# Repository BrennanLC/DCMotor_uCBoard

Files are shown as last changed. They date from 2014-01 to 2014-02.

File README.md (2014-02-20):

DCMotor_uCBoard
===============

ATmega328P Microcontroller Board with 2-CH DC Motor Driver

Design has not yet been verified. Build at your own risk!

Files:

MDM00001.sch - Board schematic eagle file

MDM00001.pdf - Board schematic PDF file

MDM00001.brd - Board layout eagle file

MDM00001Board.pdf - Board layout PDF file

schematic and board layout built with Eagle 6.4.0 Standard. More info and 
download available here:

https://www.cadsoftusa.com/

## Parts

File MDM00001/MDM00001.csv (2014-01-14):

Qty | Value | Device | Package | Parts | Description | DIGIKEYPART# | PART# | PROD_ID
4 |  | LED0603 | LED-0603 | LED1, LED2, LED3, LED4 | LEDs
1 |  | M05PTH | 1X05 | JP4 | Header 5
1 |  | PINHD-2X3 | 2X03 | JP10 | PIN HEADER
1 |  | RESONATORPTH | RESONATOR-PTH | Y1 | Resonator
7 | 0.1uF | CAP0603-CAP | 0603-CAP | C1, C4, C5, C10, C11, C12, C13 | Capacitor
3 | 10k | RESISTOR0603-RES | 0603-RES | R2, R7, R8 | Resistor
3 | 10uF | CAP_POL_AL | PANASONIC_BMIN | C3, C7, C8 | Panasonic Aluminum Electrolytic Capacitor Package B
2 | 1k | RESISTOR0603-RES | 0603-RES | R11, R12 | Resistor
2 | 2-TERMINAL | 2-TERMINAL | OSTTA020161 | JP1, JP3 | 2-Terminal Header. Based on OSTTA020161 | ED2561-ND | OSTTA020161
4 | 270 | RESISTOR0603-RES | 0603-RES | R3, R4, R9, R10 | Resistor
1 | 3SMAJ5926B-TP | 3SMAJ5926B-TP | DO-214AC | CR17 | 3SMAJ5926B-TP, 3W SMD Zener Diode, 11V Regulator | 3SMAJ5926B-TPMSCT-ND
1 | ATMEGA328P_PDIP | ATMEGA328P_PDIP | DIL28-3 | U1 | uC used in the Arduino
1 | CD4011BM | CD4011BM | 14-SOIC | U3 | CD4011 Quad NAND gate discrete logic IC | 296-14474-1-ND
2 | DRV8837DSGR | DRV8837DSGR | 8-WSON | U5, U6 | DRV8837DSGR, DC Motor Driver IC see datasheet for more information datasheet | 296-34806-1-ND
1 | FDN340P | MOSFET-PCHANNELSMD | SOT23-3 | Q1 | Generic PMOSFET
1 | FT232RLSSOP | FT232RLSSOP | SSOP28DB | U9 | USB UART |  |  | IC-00870
1 | LMV358 | LMV358 | SO08 | U$3 | Jellybean rail-to-rail output op-amp |  |  | IC-09657
1 | NCP1117ST50T3G | NCP1117ST50T3G | SOT223 | U4 | NCP1117 5V, 1.0 A Low-Dropout Positive Fixed and Adjustable Voltage Regulator Datasheet | NCP1117ST50T3GOSCT-ND
1 | POWER_JACKPTH | POWER_JACKPTH | POWER_JACK_PTH | J1 | Power Jack
1 | PTCSMD | PTCSMD | PTC-1206 | F1 | Resettable Fuse PTC
8 | SMD26PL | SMD26PL | SOD-123FL | CR1, CR2, CR3, CR4, CR5, CR6, CR7, CR8 | Schottky Barrier Diode SMD26PL | SMD26PL-TPMSCT-ND
1 | SN74HC02DR | SN74HC02DR | 14-SOIC | U10 | SN74HC02DR, Quad, Dual Input Nor Gate | 296-1188-1-ND
4 | STAND-OFF | STAND-OFF | STAND-OFF | STANDOFF1, STANDOFF2, STANDOFF3, STANDOFF4 | #4 Stand Off
1 | SWITCH | SWITCH-MOMENTARY-2PTH | TACTILE-PTH | S1 | Various NO switches- pushbuttons, reed, etc
1 | USBSMD | USBSMD | USB-MINIB | JP2 | USB Connectors

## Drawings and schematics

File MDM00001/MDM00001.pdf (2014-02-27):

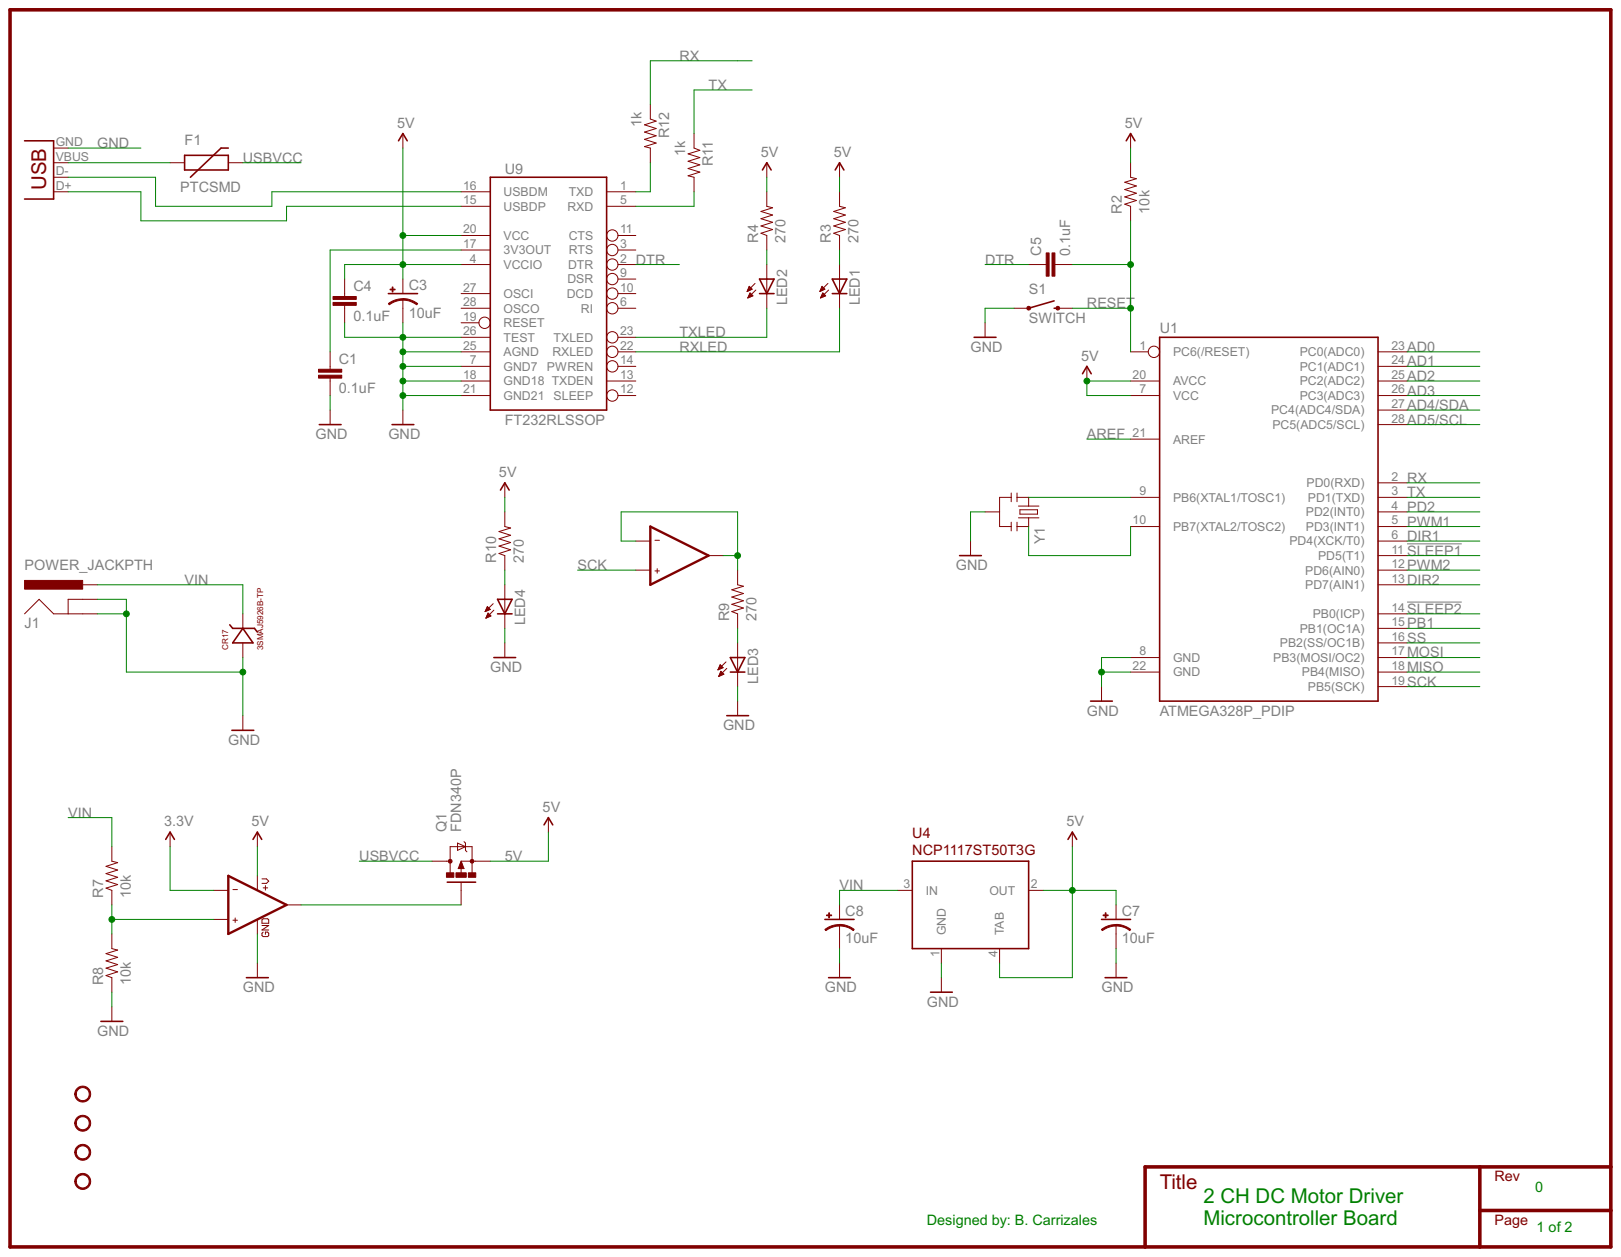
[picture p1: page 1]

Title
2 CH DC Motor Driver

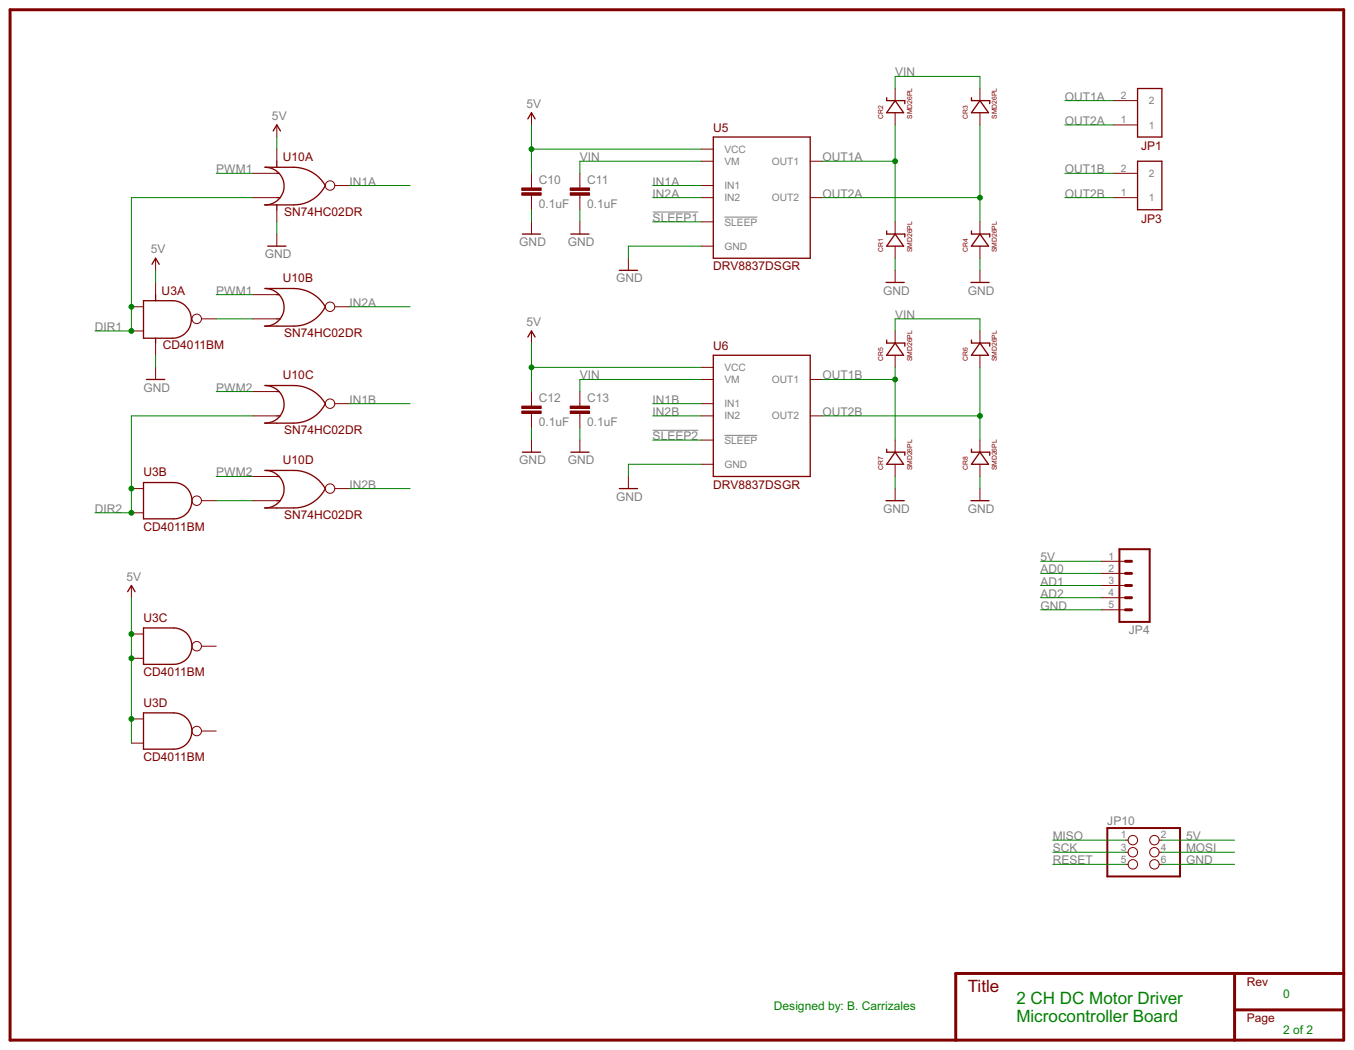
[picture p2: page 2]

2 CH DC Motor Driver
Microcontroller Board

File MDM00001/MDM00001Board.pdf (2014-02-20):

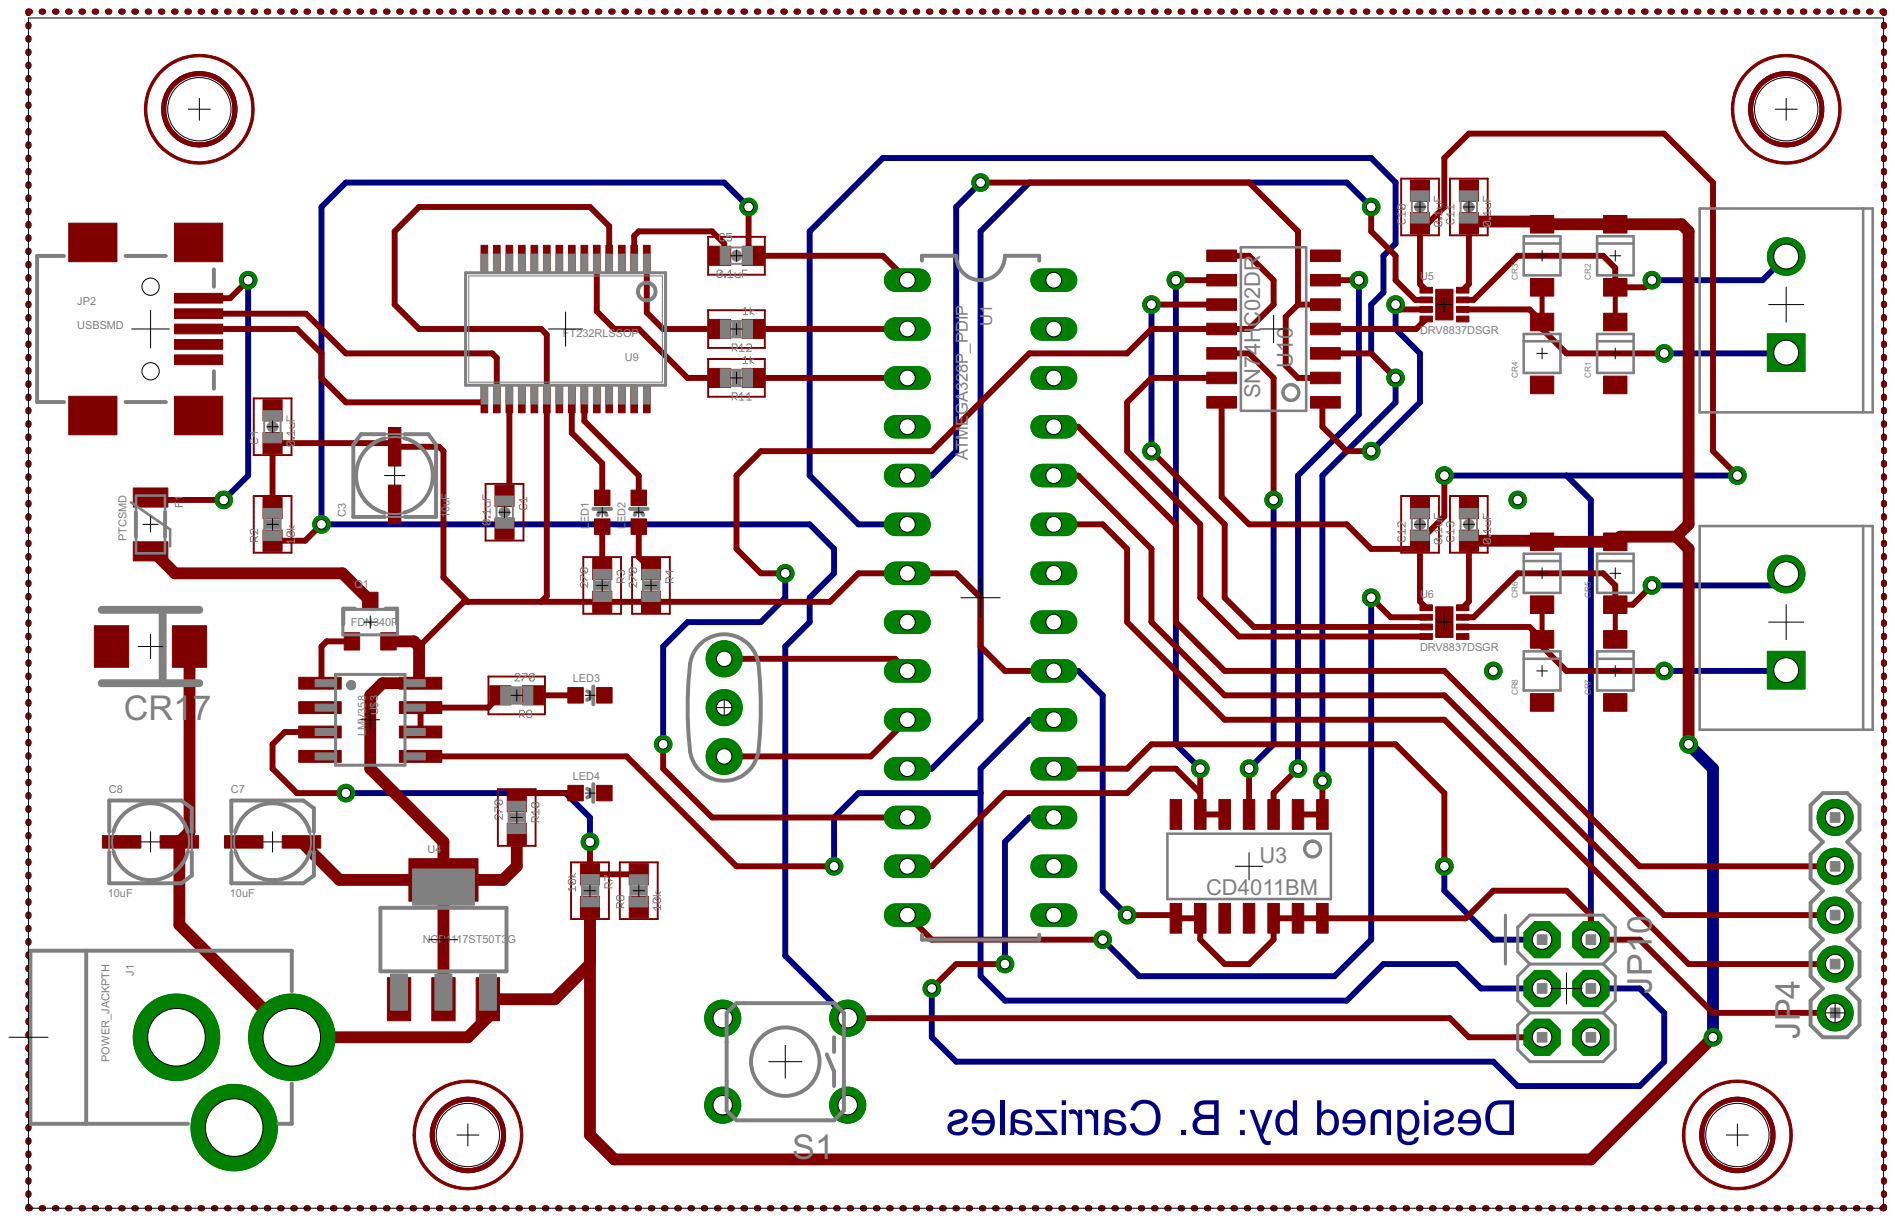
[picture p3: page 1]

sel azirr aC. B: yb dengi seD U5DRV8837DSGR U6DRV8837DSGR CR17 CD4011BM U3SN74HC02DR U10U1JP2 LED1 LEDF21 J1 CR1 CR2 CR3 CR4 CR5 CR6 CR7 CR8 JP10 U$3 Q1 LED3 LED4 U4 C8 C7 S1 C3 U9 JP4 ATMEGA328P_PDIP USBSMD PTCSMD POWER_JACKPTH LMV358 FDN340P NCP1117ST50T3G 10uF 10uF 10uF FT232RLSSOP

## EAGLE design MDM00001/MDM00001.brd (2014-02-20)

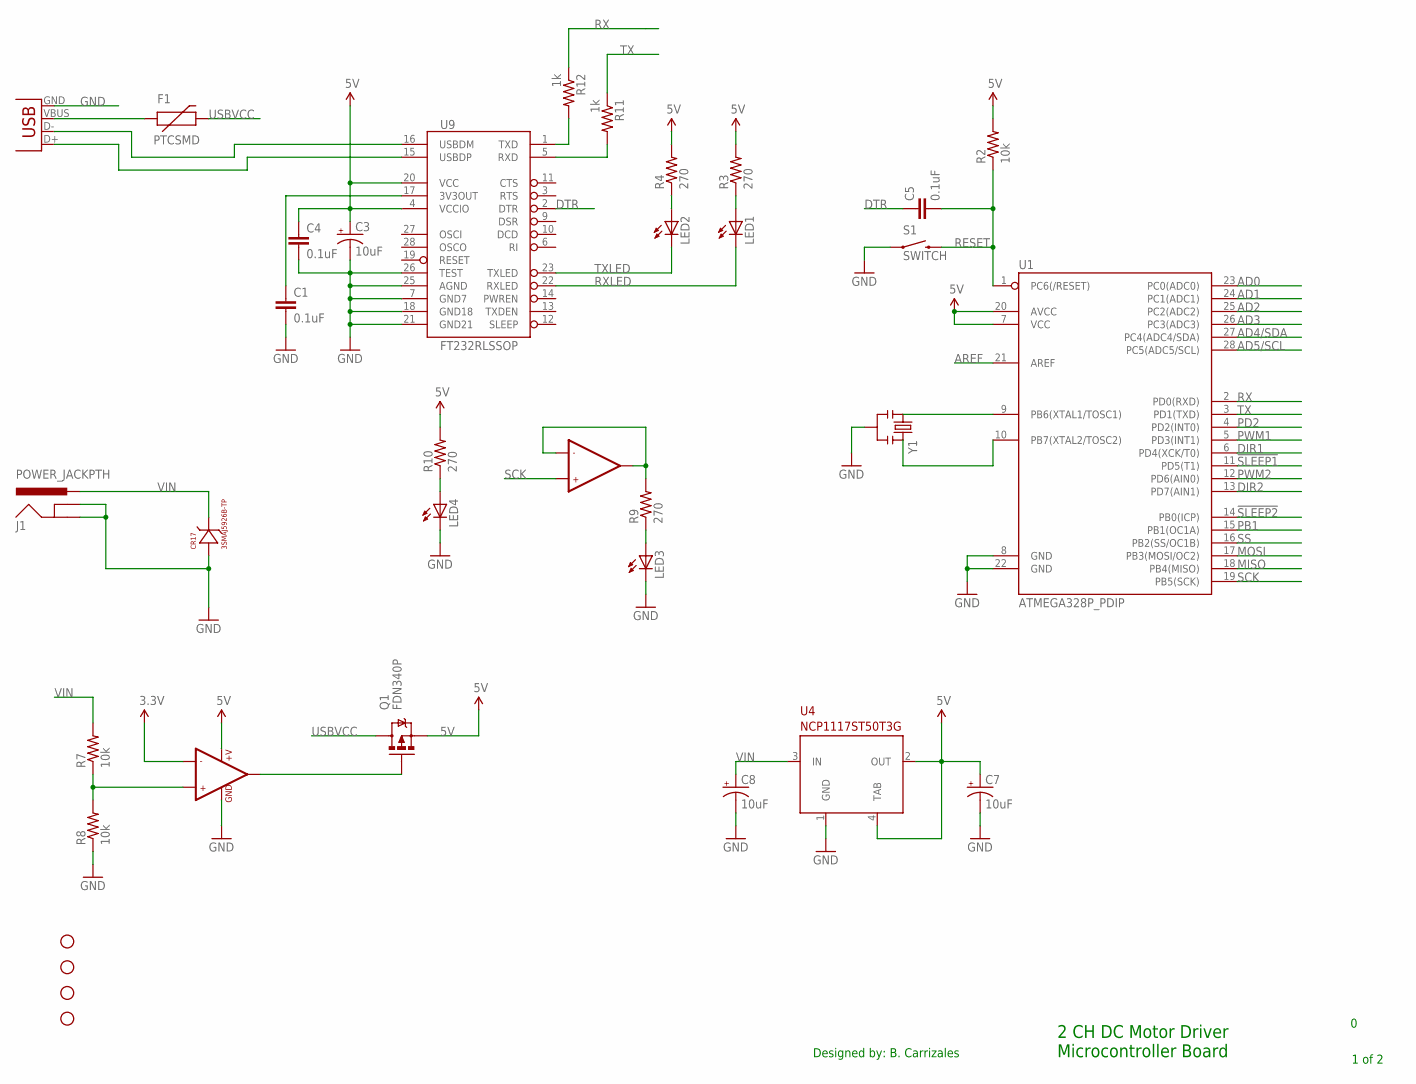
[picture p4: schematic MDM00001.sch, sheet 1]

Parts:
C1, C4, C5: 0.1uF; 0603-CAP
C3, C7, C8: 10uF; PANASONIC_BMIN
CR17: 3SMAJ5926B-TP; DO-214AC
F1: PTCSMD; PTC-1206
J1: POWER_JACKPTH; POWER_JACK_PTH
JP2: USBSMD; USB-MINIB
LED1, LED2, LED3, LED4: LED0603; LED-0603
Q1: FDN340P; SOT23-3
R2, R7, R8: 10k; 0603-RES
R3, R4, R9, R10: 270; 0603-RES
R11, R12: 1k; 0603-RES
S1: SWITCH; TACTILE-PTH
STANDOFF1, STANDOFF2, STANDOFF3, STANDOFF4: STAND-OFF
U1: ATMEGA328P_PDIP; DIL28-3
U4: NCP1117ST50T3G; SOT223
U9: FT232RLSSOP; SSOP28DB
U$3: LMV358; SO08
Y1: RESONATORPTH; RESONATOR-PTH

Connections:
3.3V: U$3.2 (-IN1)
5V: C3.+, C4.1, C7.+, Q1.2 (S), R2.2, R3.2, R4.2, R10.2, U1.7 (VCC), U1.20 (AVCC), U4.2 (OUT), U4.4 (TAB), U9.4 (VCCIO), U9.20 (VCC), U$3.8 (+V); also elsewhere on the board
!SLEEP1: U1.11 (PD5(T1)); also elsewhere on the board
!SLEEP2: U1.14 (PB0(ICP)); also elsewhere on the board
AD0: U1.23 (PC0(ADC0)); also elsewhere on the board
AD1: U1.24 (PC1(ADC1)); also elsewhere on the board
AD2: U1.25 (PC2(ADC2)); also elsewhere on the board
AD3: U1.26 (PC3(ADC3))
AD4/SDA: U1.27 (PC4(ADC4/SDA))
AD5/SCL: U1.28 (PC5(ADC5/SCL))
AREF: U1.21 (AREF)
DIR1: U1.6 (PD4(XCK/T0)); also elsewhere on the board
DIR2: U1.13 (PD7(AIN1)); also elsewhere on the board
DTR: C5.1, U9.2 (DTR)
GND: C1.2, C3.-, C4.2, C7.-, C8.-, CR17.AN, J1.GND, J1.GNDBREAK, JP2.GND, LED3.C, LED4.C, R8.1, S1.1, U1.8 (GND), U1.22 (GND), U4.1 (GND), U9.7 (GND7), U9.18 (GND18), U9.21 (GND21), U9.25 (AGND), U9.26 (TEST), U$3.4 (GND), Y1.2; also elsewhere on the board
MISO: U1.18 (PB4(MISO)); also elsewhere on the board
MOSI: U1.17 (PB3(MOSI/OC2)); also elsewhere on the board
unnamed: U1.9 (PB6(XTAL1/TOSC1)), Y1.1
unnamed: U1.10 (PB7(XTAL2/TOSC2)), Y1.3
unnamed: JP2.D-, U9.16 (USBDM)
unnamed: JP2.D+, U9.15 (USBDP)
unnamed: F1.1, JP2.VBUS
unnamed: LED2.A, R4.1
unnamed: LED1.A, R3.1
unnamed: R12.2, U9.1 (TXD)
unnamed: R11.2, U9.5 (RXD)
unnamed: R7.1, R8.2, U$3.3 (+IN1)
unnamed: LED3.A, R9.1
unnamed: R9.2, U$3.6 (-IN2), U$3.7 (OUT2)
unnamed: Q1.1 (G), U$3.1 (OUT1)
unnamed: LED4.A, R10.1
unnamed: C1.1, U9.17 (3V3OUT)
PB1: U1.15 (PB1(OC1A))
PD2: U1.4 (PD2(INT0))
PWM1: U1.5 (PD3(INT1)); also elsewhere on the board
PWM2: U1.12 (PD6(AIN0)); also elsewhere on the board
RESET: C5.2, R2.1, S1.3 (2), U1.1 (PC6(/RESET)); also elsewhere on the board
RX: R12.1, U1.2 (PD0(RXD))
RXLED: LED1.C, U9.22 (RXLED)
SCK: U1.19 (PB5(SCK)), U$3.5 (+IN2); also elsewhere on the board
SS: U1.16 (PB2(SS/OC1B))
TX: R11.1, U1.3 (PD1(TXD))
TXLED: LED2.C, U9.23 (TXLED)
USBVCC: F1.2, Q1.3 (D)
VIN: C8.+, CR17.CAT, J1.PWR, R7.2, U4.3 (IN); also elsewhere on the board

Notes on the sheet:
2 CH DC Motor Driver Microcontroller Board
1 of 2
Designed by: B. Carrizales

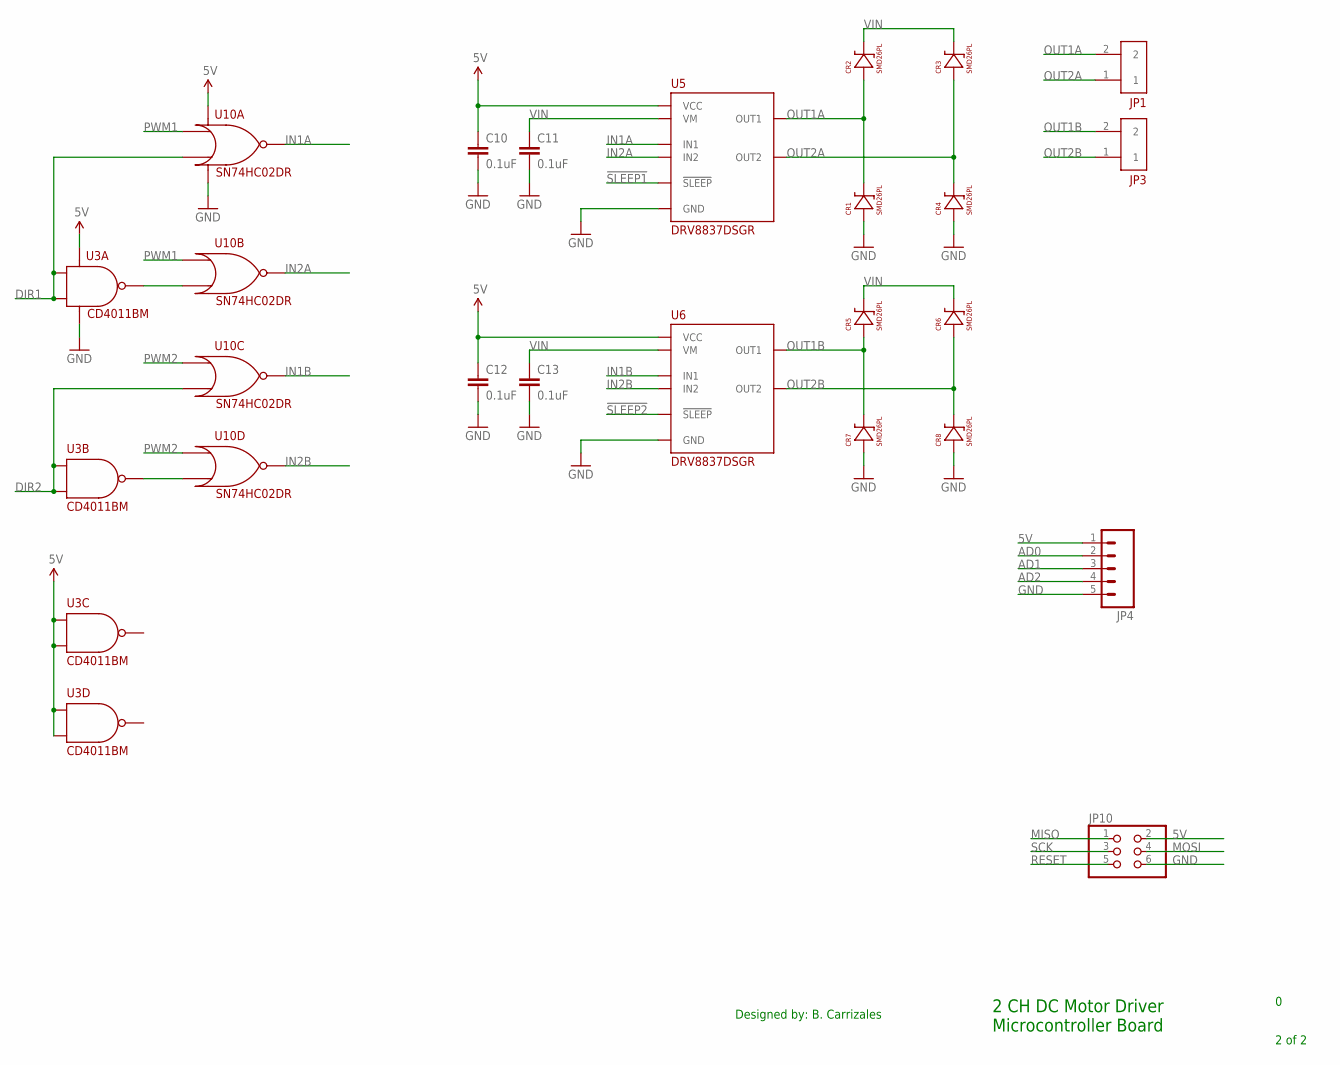
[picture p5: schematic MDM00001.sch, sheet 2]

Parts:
C10, C11, C12, C13: 0.1uF; 0603-CAP
CR1, CR2, CR3, CR4, CR5, CR6, CR7, CR8: SMD26PL; SOD-123FL
JP1, JP3: 2-TERMINAL; OSTTA020161
JP4: M05PTH; 1X05
JP10: PINHD-2X3; 2X03
U3: CD4011BM; 14-SOIC
U5, U6: DRV8837DSGR; 8-WSON
U10: SN74HC02DR; 14-SOIC

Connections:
5V: C10.1, C12.1, JP4.1, JP10.2, U3.8 (I0), U3.9 (I1), U3.12 (I0), U3.13 (I1), U3.14, U5.P$8 (VCC), U6.P$8 (VCC), U10.14; also elsewhere on the board
!SLEEP1: U5.P$7 (!SLEEP); also elsewhere on the board
!SLEEP2: U6.P$7 (!SLEEP); also elsewhere on the board
AD0: JP4.2; also elsewhere on the board
AD1: JP4.3; also elsewhere on the board
AD2: JP4.4; also elsewhere on the board
DIR1: U3.1 (I0), U3.2 (I1), U10.3 (I1); also elsewhere on the board
DIR2: U3.5 (I0), U3.6 (I1), U10.9 (I1); also elsewhere on the board
GND: C10.2, C11.2, C12.2, C13.2, CR1.1, CR4.1, CR7.1, CR8.1, JP4.5, JP10.6, U3.7, U5.P$4 (GND), U6.P$4 (GND), U10.7; also elsewhere on the board
IN1A: U5.P$6 (IN1), U10.1 (O1)
IN1B: U6.P$6 (IN1), U10.10 (O1)
IN2A: U5.P$5 (IN2), U10.4 (O1)
IN2B: U6.P$5 (IN2), U10.13 (O1)
MISO: JP10.1; also elsewhere on the board
MOSI: JP10.4; also elsewhere on the board
unnamed: U3.4 (O1), U10.12 (I1)
unnamed: U3.3 (O1), U10.6 (I1)
OUT1A: CR1.2, CR2.1, JP1.2, U5.P$2 (OUT1)
OUT1B: CR5.1, CR7.2, JP3.2, U6.P$2 (OUT1)
OUT2A: CR3.1, CR4.2, JP1.1, U5.P$3 (OUT2)
OUT2B: CR6.1, CR8.2, JP3.1, U6.P$3 (OUT2)
PWM1: U10.2 (I0), U10.5 (I0); also elsewhere on the board
PWM2: U10.8 (I0), U10.11 (I0); also elsewhere on the board
RESET: JP10.5; also elsewhere on the board
SCK: JP10.3; also elsewhere on the board
VIN: C11.1, C13.1, CR2.2, CR3.2, CR5.2, CR6.2, U5.P$1 (VM), U6.P$1 (VM); also elsewhere on the board

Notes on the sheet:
2 CH DC Motor Driver Microcontroller Board
2 of 2
Designed by: B. Carrizales

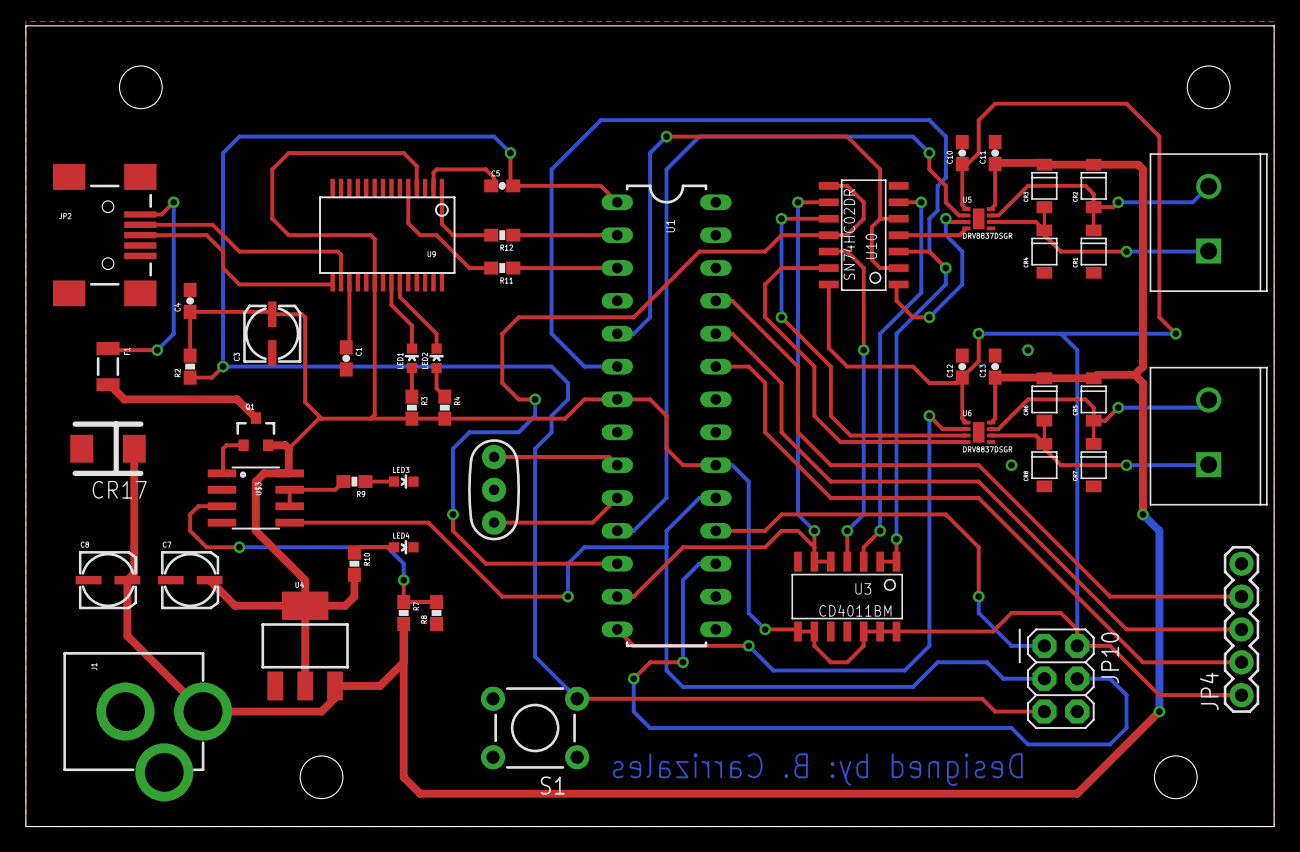
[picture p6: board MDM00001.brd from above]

Board: 2 copper layers, 96.5 x 61.9 mm, 54 parts (0 on the bottom side), 47 nets.

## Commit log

2014-01-10 Initial Commit
    Initial Commit
    [MDM00001.sch]
2014-01-12 Finished Schematic
    Revision 0 of schematic complete. Generated bill of materials
    [MDM00001.csv]
2014-01-14 Finished Major Layout
    Finished major layout and updated schematic. Regenerated BOM.
    [MDM00001.brd, MDM00001.csv, MDM00001.sch]
2014-02-20 Updated README and added PDF Files
    [MDM00001.brd, MDM00001.sch]

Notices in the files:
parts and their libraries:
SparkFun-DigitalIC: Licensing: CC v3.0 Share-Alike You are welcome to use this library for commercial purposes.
